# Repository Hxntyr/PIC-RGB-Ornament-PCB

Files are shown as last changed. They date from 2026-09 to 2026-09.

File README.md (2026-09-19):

# PIC RGB Ornament PCB

A template for making — and a collection of — small RGB LED PCB ornaments.

The core circuit uses a PIC12F1572, CR2450R coin cell, and MCP1640 boost converter to drive 24 low-current RGB LEDs through three shared PWM channels. It is intended to be reused across different board shapes, artwork, and LED layouts without redesigning the electronics each time.

Copy the core project, make your own layout, generate the manufacturing files, and send it off for PCBA — or [purchase the components and assemble it yourself](https://www.digikey.com/en/mylists/list/D7LT6KEKSW).

<p align="center">
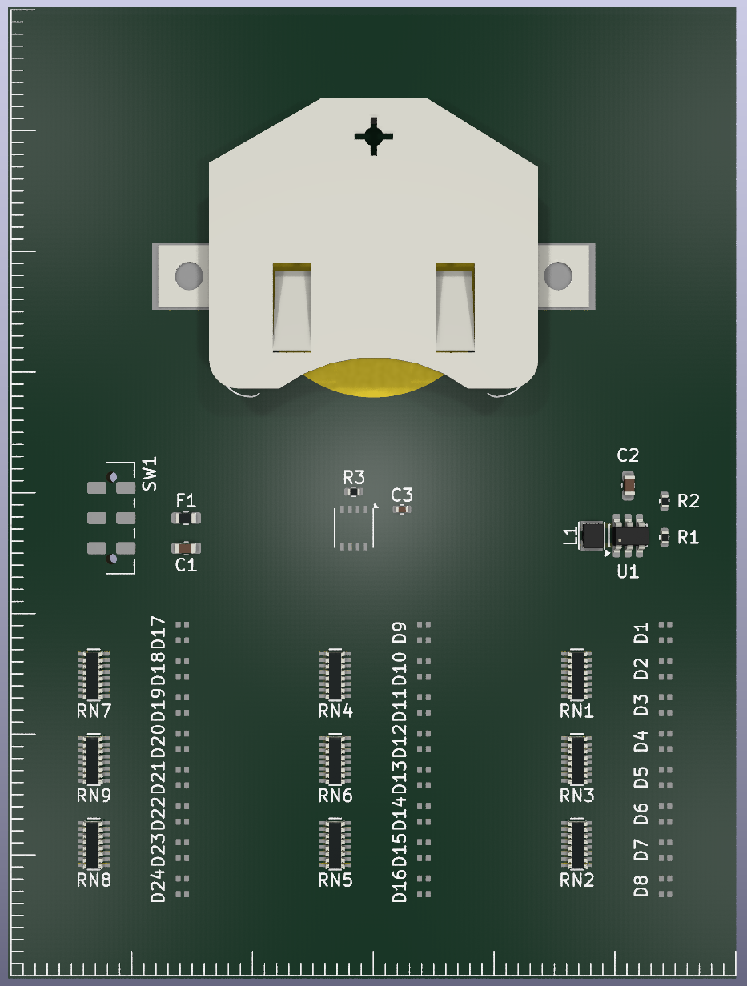
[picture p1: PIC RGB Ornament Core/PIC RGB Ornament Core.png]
PIC RGB Ornament Core
  
</p>

## What's Included

The [`PIC RGB Ornament Core`](PIC%20RGB%20Ornament%20Core/) folder contains the reusable KiCad project.

Reference files:

* [`PIC RGB Ornament Core_Schematic.pdf`](PIC%20RGB%20Ornament%20Core/PIC%20RGB%20Ornament%20Core_Schematic.pdf) — schematic
* [`PIC RGB Ornament Core_PCB.pdf`](PIC%20RGB%20Ornament%20Core/PIC%20RGB%20Ornament%20Core_PCB.pdf) — component layout with a millimeter scale for quick size reference
* [`PIC RGB Ornament Core.png`](PIC%20RGB%20Ornament%20Core/PIC%20RGB%20Ornament%20Core.png) — 3D viewer reference

Custom footprints are stored in the repository-level [`HX.pretty`](HX.pretty/) library. Each included KiCad project references this library through its local `fp-lib-table`.

The core [`PCBA`](PIC%20RGB%20Ornament%20Core/PCBA/) folder contains files that can generally be reused between designs:

* `BOM.xlsx`
* `FIRMWARE.zip`

The supplied firmware continuously cycles through a slow rainbow at conservative brightness. The PIC is intended to be programmed during assembly, so the finished ornament requires no configuration.

## Making an Ornament

Clone or download the repository and make a copy of the `PIC RGB Ornament Core` project, or use one of the existing ornaments as a starting point.

The electrical design can generally remain unchanged. Modify the board outline, component placement, LED arrangement, artwork, mounting features, and routing as needed for the new design.

If additional custom footprints are required, add them to the root `HX.pretty` library. Projects located one directory below the repository root can use the same `fp-lib-table` entry:

```scheme
(fp_lib_table
  (version 7)
  (lib (name "HX")(type "KiCad")(uri "${KIPRJMOD}/../HX.pretty")(options "")(descr "Project custom footprints"))
)
```

## Preparing a Layout for PCBA

The BOM and firmware can normally be reused as long as the circuit and component selections remain unchanged.

The remaining manufacturing files are layout-specific and should be regenerated for each ornament.

### Gerbers and Drill Files

From KiCad PCB Editor:

`File → Fabrication Outputs → Gerbers`

Export the required copper, solder mask, silkscreen, paste, and `Edge.Cuts` layers, then generate the Excellon drill files.

Zip the Gerber and drill outputs together for fabrication.

### CPL / Pick-and-Place

From KiCad PCB Editor:

`File → Fabrication Outputs → Component Placement`

Export the placement file in millimeters with reference designator, X/Y coordinates, rotation, and board side.

PCBWay refers to this as the **CPL** or centroid file.

### Assembly Drawings

Plot `F.Fab` and `B.Fab` as PDFs with the board outline visible.

These provide a simple component-location and orientation reference for assembly.

### BOM

The baseline BOM is included at:

`PIC RGB Ornament Core/PCBA/BOM.xlsx`

Regenerate or edit it if component values, part numbers, or designators change.

### PIC Firmware

Production firmware is included at:

`PIC RGB Ornament Core/PCBA/FIRMWARE.zip`

For turnkey assembly, program:

`U2 — PIC12F1572T-I/MF`

using the supplied `.hex` file before assembly.

Example production note:

> Program U2 before assembly using the supplied HEX file. After assembly, power the board and verify that all 24 RGB LEDs smoothly cycle through the rainbow.

## Example

[`HappyBirthdayMickey_A`](HappyBirthdayMickey_A/) is an example ornament built from the core design.

Its `PCBA` folder contains a complete set of layout-specific production files:

* Gerber and drill ZIP
* BOM
* CPL / pick-and-place file
* assembly drawing PDFs
* firmware

These are included as a reference for what a completed manufacturing package looks like rather than as production files for the generic core.

## Notes

The default firmware intentionally runs the LEDs fairly dim to reduce coin-cell current and keep the ornament comfortable to view in a dark room.

The CR2450R battery should be installed **after** PCB assembly and should not go through reflow.

## License

This project is released under the **CC0 1.0 Universal Public Domain Dedication**.

Use it, modify it, manufacture it, remix it, or turn it into something completely different.

See [`LICENSE`](LICENSE).

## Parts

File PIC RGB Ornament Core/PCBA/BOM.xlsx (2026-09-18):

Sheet: PCBWay BOM
PIC RGB Ornament PCB — PCBWay Assembly BOM
14 unique assembly line items • 45 total placed components • CR2450R battery excluded from reflow BOM
Item | Designator | Qty | Value | Description | Manufacturer | MFG Part Number | Package / Footprint | Assembly Type | Assembly Notes | Datasheet
1 | U1 | 1 | MCP1640 | 500 kHz synchronous PWM/PFM boost regulator, true output disconnect | Microchip Technology | MCP1640T-I/CHY | SOT-23-6 | SMD |  | https://ww1.microchip.com/downloads/aemDocuments/documents/APID/ProductDocuments/DataSheets/MCP1640-Family-Data-Sheet-DS20002234E.pdf
2 | U2 | 1 | PIC12F1572 | 8-bit MCU with 3× 16-bit PWM channels and internal oscillator | Microchip Technology | PIC12F1572T-I/MF | DFN-8, 3×3 mm, 0.65 mm pitch | SMD | PROGRAM BEFORE ASSEMBLY. Firmware file: PIC_RGB_Ornament.hex. Do not substitute MCU without approval. | https://ww1.microchip.com/downloads/en/DeviceDoc/40001723D.pdf
3 | D1-D24 | 24 | RGB | Low-current common-anode RGB LED, 1.6×0.8×0.5 mm | Kingbright | APHF1608LSEEQBDZGKC | 4-SMD, 1.6×0.8 mm | SMD | Observe polarity/orientation. Exact optical part preferred. | https://www.kingbrightusa.com/images/catalog/SPEC/APHF1608LSEEQBDZGKC.pdf
4 | RN1,RN4,RN7 | 3 | 8.2 kΩ ×8 | 8 isolated resistor elements; red LED current limiting | Panasonic | EXB2HV822JV | EXB-2HV, 16-pad resistor array | SMD |  | https://industrial.panasonic.com/cdbs/www-data/pdf/AOC0000/AOC0000C14.pdf
5 | RN2,RN3,RN5,RN6,RN8,RN9 | 6 | 3.9 kΩ ×8 | 8 isolated resistor elements; green/blue LED current limiting | Panasonic | EXB2HV392JV | EXB-2HV, 16-pad resistor array | SMD |  | https://industrial.panasonic.com/cdbs/www-data/pdf/AOC0000/AOC0000C14.pdf
6 | R1 | 1 | 309 kΩ | MCP1640 feedback lower resistor, 1% | Yageo | RC0402FR-07309KL | 0402 / 1005 metric | SMD |  | https://yageogroup.com/content/datasheet/asset/file/PYU-RC_GROUP_51_ROHS_L
7 | R2 | 1 | 604 kΩ | MCP1640 feedback upper resistor, 1% | Yageo | RC0402FR-07604KL | 0402 / 1005 metric | SMD |  | https://yageogroup.com/content/datasheet/asset/file/PYU-RC_GROUP_51_ROHS_L
8 | R3 | 1 | 10 kΩ | PIC MCLR pull-up resistor, 1% | Yageo | RC0402FR-0710KL | 0402 / 1005 metric | SMD |  | https://yageogroup.com/content/datasheet/asset/file/PYU-RC_GROUP_51_ROHS_L
9 | C1,C2 | 2 | 10 µF | Boost converter input/output MLCC, 10 V X5R | Murata | GRM188R61A106ME69 | 0603 / 1608 metric | SMD |  | https://mm.digikey.com/Volume0/opasdata/d220001/medias/docus/8942/490_Chip_Multilayer_CAT2021_MLCC.pdf
10 | C3 | 1 | 100 nF | PIC local VDD decoupling MLCC | Murata | GRM155R71C104KA88J | 0402 / 1005 metric | SMD |  | https://mm.digikey.com/Volume0/opasdata/d220001/medias/docus/8942/490_Chip_Multilayer_CAT2021_MLCC.pdf
11 | L1 | 1 | 4.7 µH | Shielded boost-converter inductor, 1.1 A | Murata | LQM2MPN4R7MG0L | 2.0×1.6 mm power inductor | SMD |  | https://pim.murata.com/asset/pim4/inductor/JELF243B-0022_PDF_INDUCTOR
12 | F1 | 1 | 50 mA hold | Resettable PPTC battery protection fuse | Eaton | PTS060315V005 | 0603 / 1608 metric | SMD |  | https://www.eaton.com/content/dam/eaton/products/electronic-components/resources/data-sheet/eaton-pts0603-surface-mount-resettable-fuse-data-sheet-elx1046-en.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
13 | SW1 | 1 | SPDT ON-ON | Right-angle SMT slide power switch | C&K | JS102011JAQN | JS series right-angle SMT | SMD | Observe mechanical orientation at board edge. | https://www.littelfuse.com/assetdocs/littelfuse-c-k-slide-js-series-datasheet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
14 | BT1 | 1 | 3088TR | SMT coin-cell holder/retainer for 24.5 mm cell | Keystone Electronics | 3088TR | SMT CR2450 holder | SMD | Battery itself is not reflow assembled; install CR2450R after PCBA. | https://www.keyelco.com/userAssets/file/K75p11.pdf

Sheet: Non-PCBA
Non-PCBA / Production Items
Item | Qty | Description | Manufacturer | Part Number | Handling / Notes | Datasheet
CR2450R battery | 1 | 3 V high-drain lithium coin cell, ~500 mAh | Murata | CR2450R | Do not send through reflow. Install after assembly / before gifting. Recommended cell for the design. | https://www.murata.com/-/media/webrenewal/products/batteries/micro/cr/high-drain/ds-cr2450r-004-je_202307.ashx
PIC firmware | 1 | Production firmware image for U2 | Project file | PIC_RGB_Ornament.hex | Provide to PCBWay with instruction to program U2 before assembly.

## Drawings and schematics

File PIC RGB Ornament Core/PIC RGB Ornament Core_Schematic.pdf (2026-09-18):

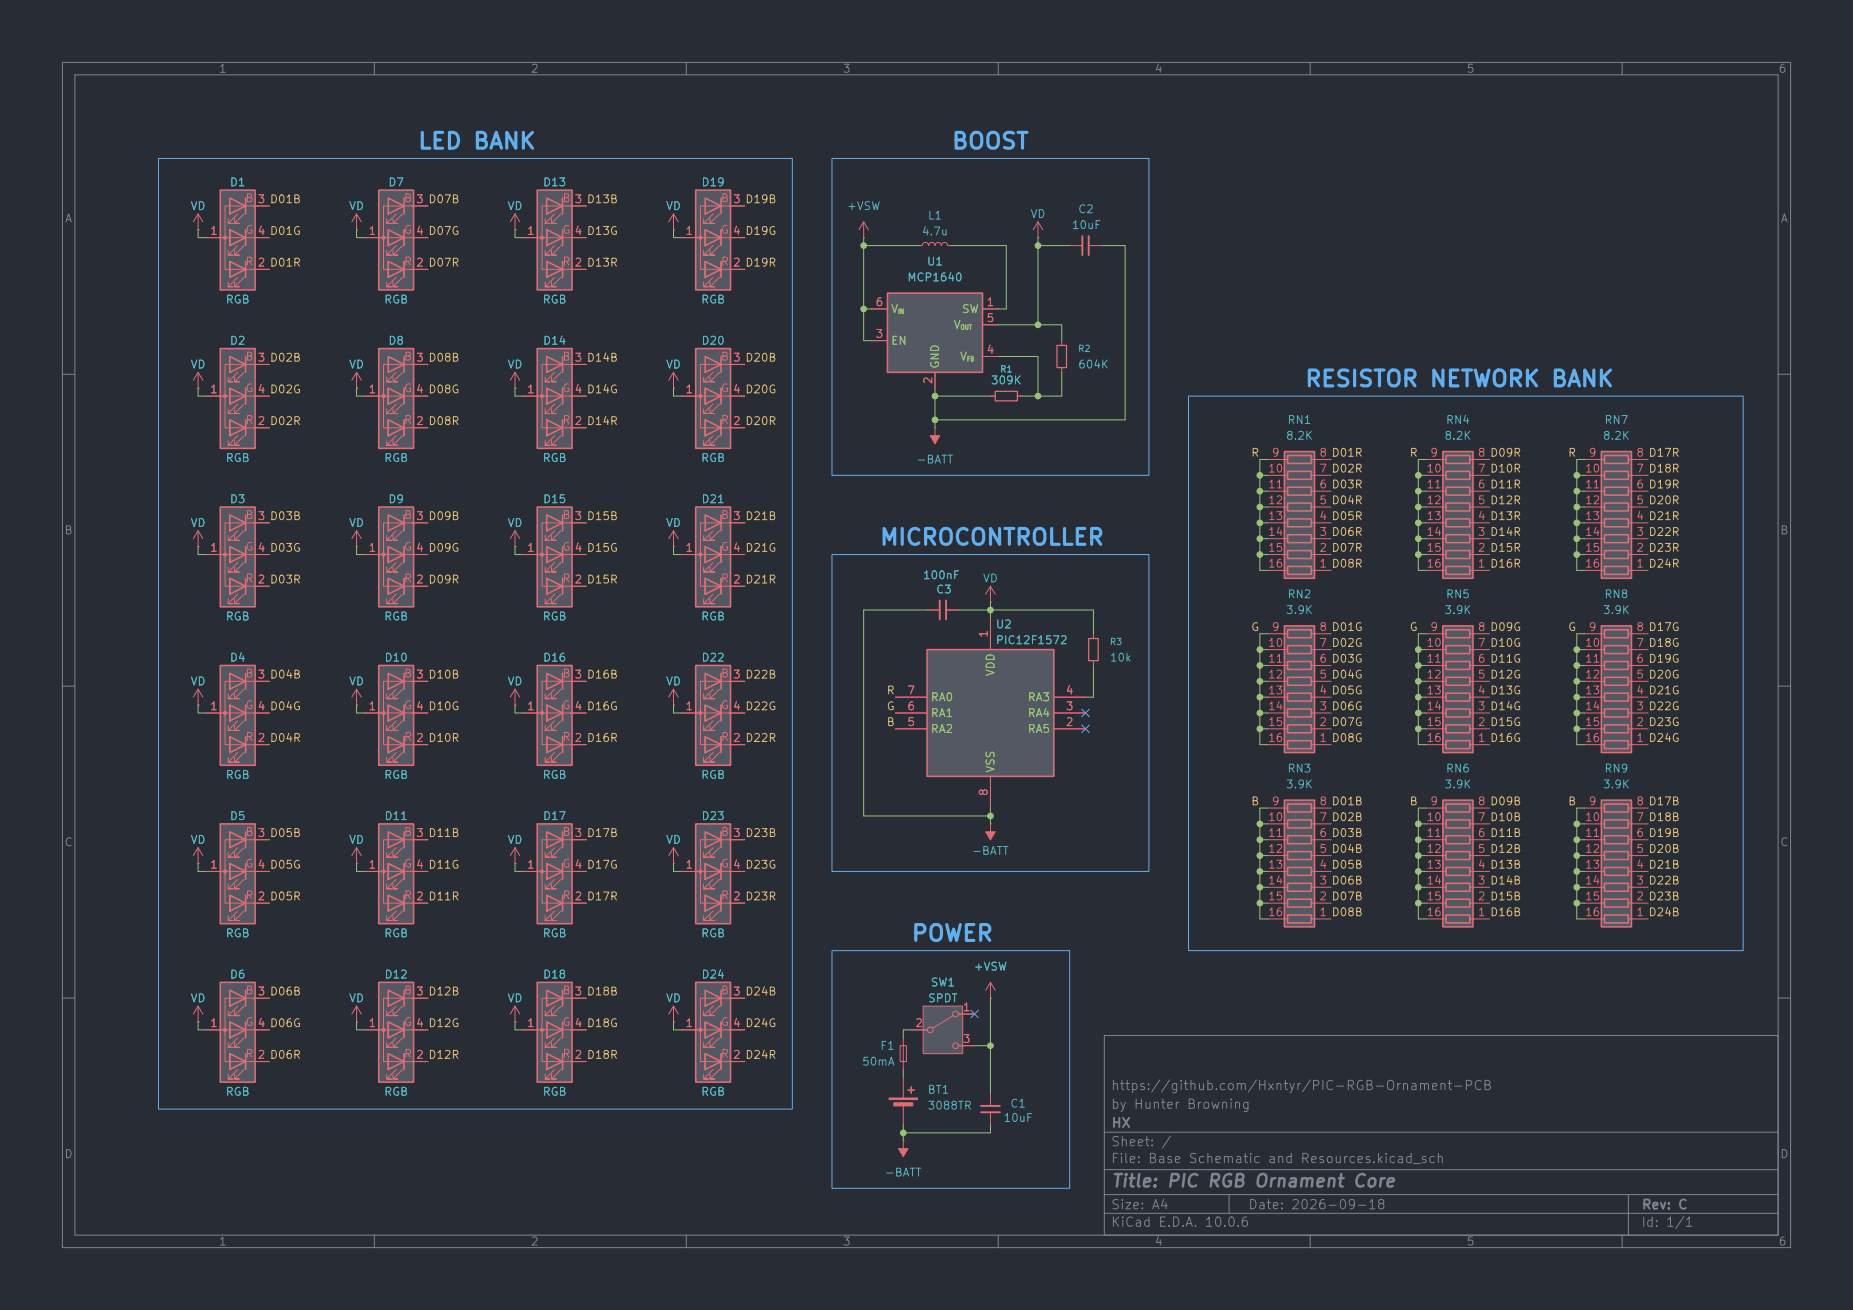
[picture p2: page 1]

https://github.com/Hxntyr/PIC-RGB-Ornament-PCB
by Hunter Browning
Sheet: /
File: Base Schematic and Resources.kicad_sch
Title: PIC RGB Ornament Core

Size: A4 | Rev: C
KiCad E.D.A. 10.0.6 | Id: 1/1

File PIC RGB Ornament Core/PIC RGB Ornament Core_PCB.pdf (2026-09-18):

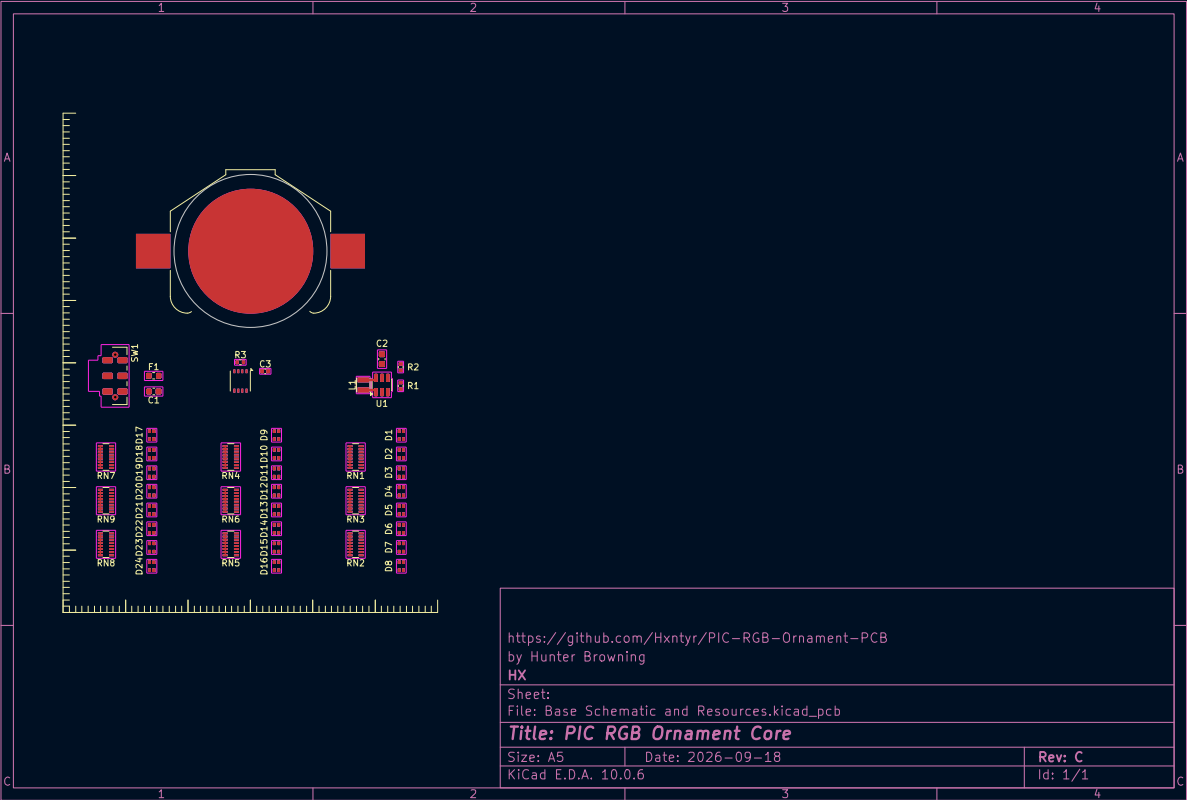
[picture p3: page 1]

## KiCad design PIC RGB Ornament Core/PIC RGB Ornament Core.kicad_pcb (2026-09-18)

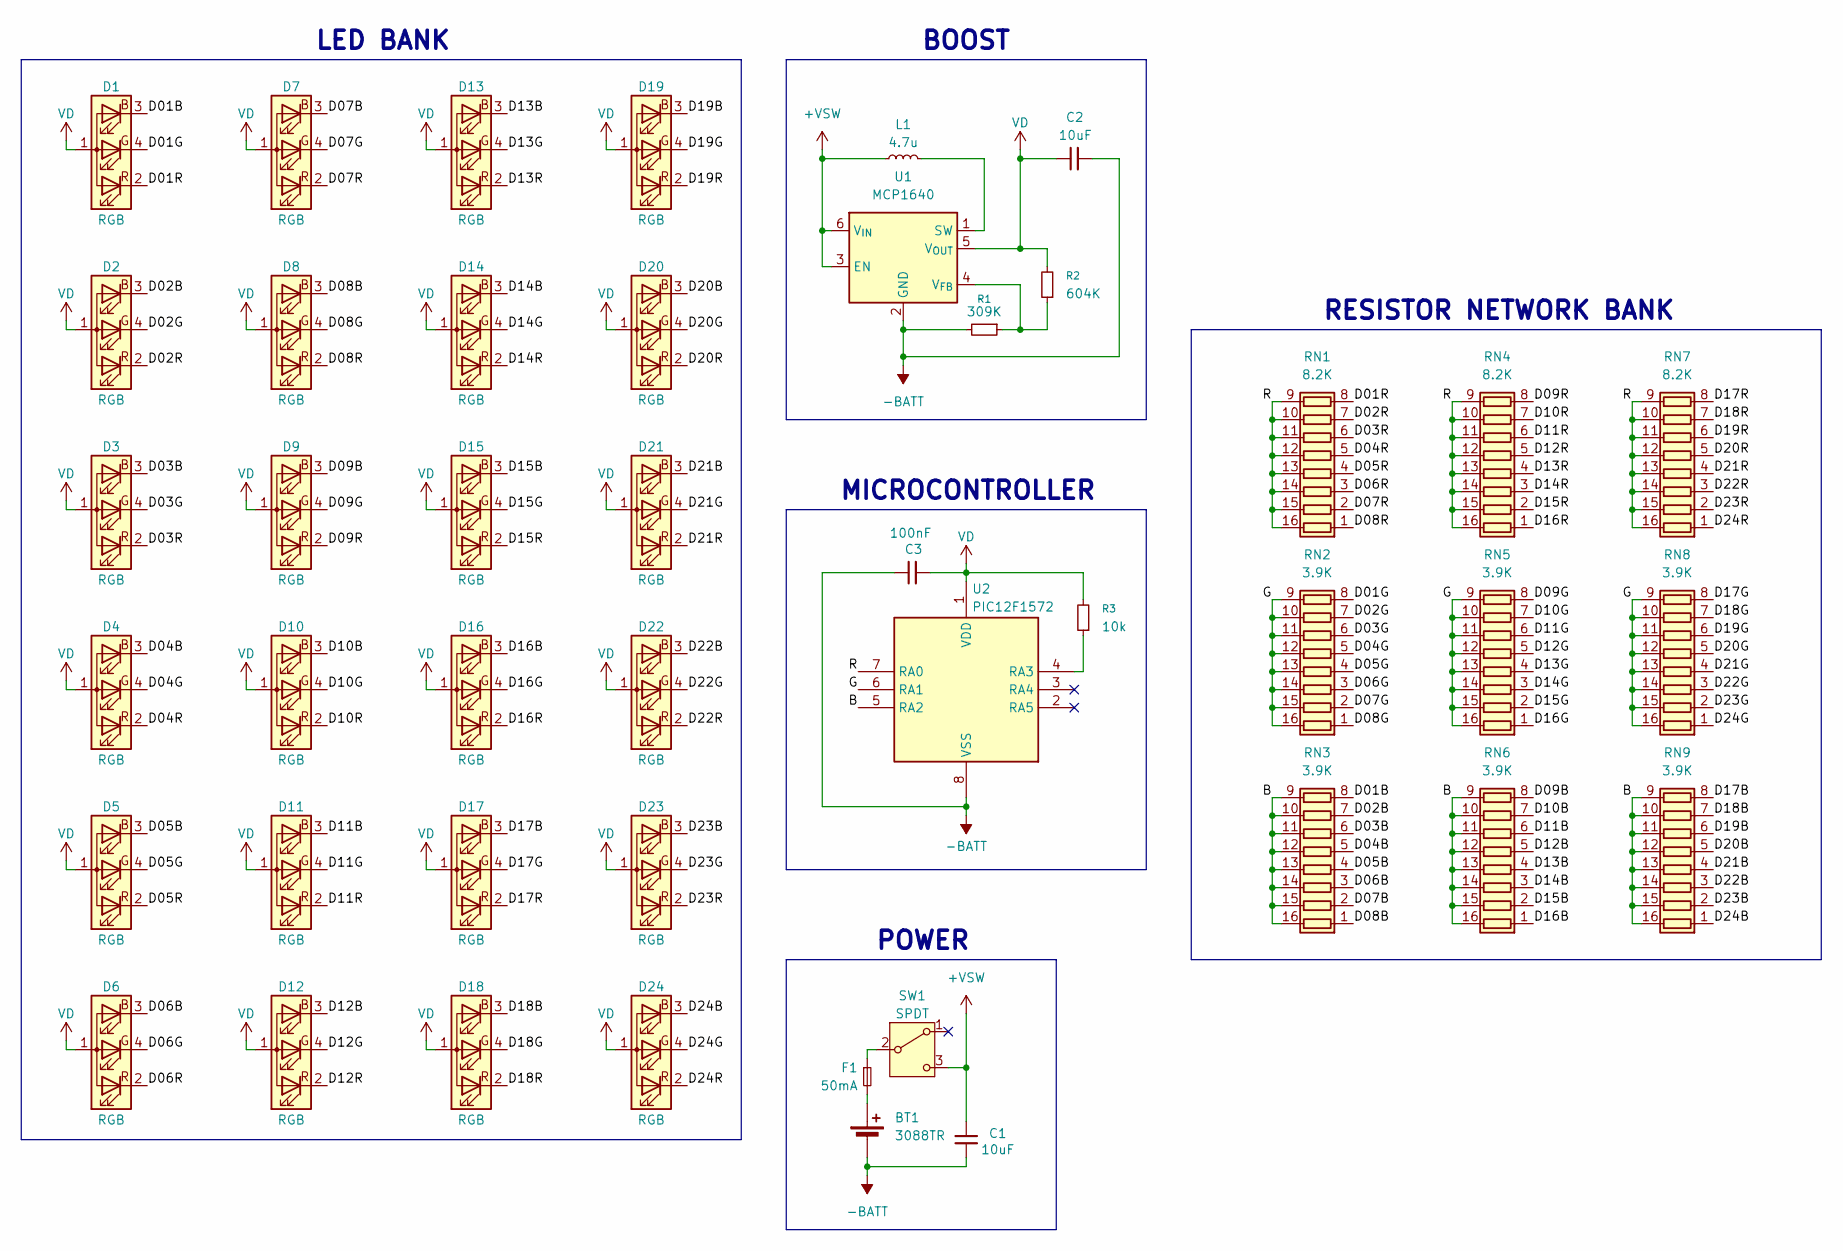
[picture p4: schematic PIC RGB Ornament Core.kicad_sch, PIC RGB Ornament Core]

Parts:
BT1: 3088TR; Keystone_3088TR; MPN 3088TR
C1, C2: 10uF; C_0603_1608Metric; MPN GRM188R61A106ME69
C3: 100nF; C_0402_1005Metric; MPN GRM155R71C104KA88J
D1, D2, D3, D4, D5, D6, D7, D8, D9, D10, D11, D12, D13, D14, D15, D16, D17, D18, D19, D20, D21, D22, D23, D24: RGB; Kingbright_APHF1608LSEEQBDZGKC; MPN APHF1608LSEEQBDZGKC
F1: 50mA; Fuse_0603_1608Metric; MPN PTS060315V005
L1: 4.7u; Murata_LQM2MPN4R7MG0L; MPN LQM2MPN4R7MG0L
R1: 309K; R_0402_1005Metric; MPN RC0402FR-07309KL
R2: 604K; R_0402_1005Metric; MPN RC0402FR-07604KL
R3: 10k; R_0402_1005Metric; MPN RC0402FR-0710KL
RN1, RN4, RN7: 8.2K; R_Array_Convex_8x0602; MPN EXB2HV822JV
RN2, RN3, RN5, RN6, RN8, RN9: 3.9K; R_Array_Convex_8x0602; MPN EXB2HV392JV
SW1: SPDT; CK_JS102011JAQN; MPN JS102011JAQN
U1: MCP1640; SOT-23-6; MPN MCP1640T-I/CHY
U2: PIC12F1572; Microchip_PIC12F1572T-IMF; MPN PIC12F1572T-I/MF

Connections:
+VSW: C1.1, L1.2, SW1.3 (C), U1.3 (EN), U1.6 (V_{IN})
-BATT: BT1.2 (-), C1.2, C2.2, C3.2, R1.2, U1.2 (GND), U2.8 (VSS)
/B: RN3.9 (R8.2), RN3.10 (R7.2), RN3.11 (R6.2), RN3.12 (R5.2), RN3.13 (R4.2), RN3.14 (R3.2), RN3.15 (R2.2), RN3.16 (R1.2), RN6.9 (R8.2), RN6.10 (R7.2), RN6.11 (R6.2), RN6.12 (R5.2), RN6.13 (R4.2), RN6.14 (R3.2), RN6.15 (R2.2), RN6.16 (R1.2), RN9.9 (R8.2), RN9.10 (R7.2), RN9.11 (R6.2), RN9.12 (R5.2), RN9.13 (R4.2), RN9.14 (R3.2), RN9.15 (R2.2), RN9.16 (R1.2), U2.5 (RA2)
/D01B: D1.3 (BK), RN3.8 (R8.1)
/D01G: D1.4 (GK), RN2.8 (R8.1)
/D01R: D1.2 (RK), RN1.8 (R8.1)
/D02B: D2.3 (BK), RN3.7 (R7.1)
/D02G: D2.4 (GK), RN2.7 (R7.1)
/D02R: D2.2 (RK), RN1.7 (R7.1)
/D03B: D3.3 (BK), RN3.6 (R6.1)
/D03G: D3.4 (GK), RN2.6 (R6.1)
/D03R: D3.2 (RK), RN1.6 (R6.1)
/D04B: D4.3 (BK), RN3.5 (R5.1)
/D04G: D4.4 (GK), RN2.5 (R5.1)
/D04R: D4.2 (RK), RN1.5 (R5.1)
/D05B: D5.3 (BK), RN3.4 (R4.1)
/D05G: D5.4 (GK), RN2.4 (R4.1)
/D05R: D5.2 (RK), RN1.4 (R4.1)
/D06B: D6.3 (BK), RN3.3 (R3.1)
/D06G: D6.4 (GK), RN2.3 (R3.1)
/D06R: D6.2 (RK), RN1.3 (R3.1)
/D07B: D7.3 (BK), RN3.2 (R2.1)
/D07G: D7.4 (GK), RN2.2 (R2.1)
/D07R: D7.2 (RK), RN1.2 (R2.1)
/D08B: D8.3 (BK), RN3.1 (R1.1)
/D08G: D8.4 (GK), RN2.1 (R1.1)
/D08R: D8.2 (RK), RN1.1 (R1.1)
/D09B: D9.3 (BK), RN6.8 (R8.1)
/D09G: D9.4 (GK), RN5.8 (R8.1)
/D09R: D9.2 (RK), RN4.8 (R8.1)
/D10B: D10.3 (BK), RN6.7 (R7.1)
/D10G: D10.4 (GK), RN5.7 (R7.1)
/D10R: D10.2 (RK), RN4.7 (R7.1)
/D11B: D11.3 (BK), RN6.6 (R6.1)
/D11G: D11.4 (GK), RN5.6 (R6.1)
/D11R: D11.2 (RK), RN4.6 (R6.1)
/D12B: D12.3 (BK), RN6.5 (R5.1)
/D12G: D12.4 (GK), RN5.5 (R5.1)
/D12R: D12.2 (RK), RN4.5 (R5.1)
/D13B: D13.3 (BK), RN6.4 (R4.1)
/D13G: D13.4 (GK), RN5.4 (R4.1)
/D13R: D13.2 (RK), RN4.4 (R4.1)
/D14B: D14.3 (BK), RN6.3 (R3.1)
/D14G: D14.4 (GK), RN5.3 (R3.1)
/D14R: D14.2 (RK), RN4.3 (R3.1)
/D15B: D15.3 (BK), RN6.2 (R2.1)
/D15G: D15.4 (GK), RN5.2 (R2.1)
/D15R: D15.2 (RK), RN4.2 (R2.1)
/D16B: D16.3 (BK), RN6.1 (R1.1)
/D16G: D16.4 (GK), RN5.1 (R1.1)
/D16R: D16.2 (RK), RN4.1 (R1.1)
/D17B: D17.3 (BK), RN9.8 (R8.1)
/D17G: D17.4 (GK), RN8.8 (R8.1)
/D17R: D17.2 (RK), RN7.8 (R8.1)
/D18B: D18.3 (BK), RN9.7 (R7.1)
/D18G: D18.4 (GK), RN8.7 (R7.1)
/D18R: D18.2 (RK), RN7.7 (R7.1)
/D19B: D19.3 (BK), RN9.6 (R6.1)
/D19G: D19.4 (GK), RN8.6 (R6.1)
/D19R: D19.2 (RK), RN7.6 (R6.1)
/D20B: D20.3 (BK), RN9.5 (R5.1)
/D20G: D20.4 (GK), RN8.5 (R5.1)
/D20R: D20.2 (RK), RN7.5 (R5.1)
/D21B: D21.3 (BK), RN9.4 (R4.1)
/D21G: D21.4 (GK), RN8.4 (R4.1)
/D21R: D21.2 (RK), RN7.4 (R4.1)
/D22B: D22.3 (BK), RN9.3 (R3.1)
/D22G: D22.4 (GK), RN8.3 (R3.1)
/D22R: D22.2 (RK), RN7.3 (R3.1)
/D23B: D23.3 (BK), RN9.2 (R2.1)
/D23G: D23.4 (GK), RN8.2 (R2.1)
/D23R: D23.2 (RK), RN7.2 (R2.1)
/D24B: D24.3 (BK), RN9.1 (R1.1)
/D24G: D24.4 (GK), RN8.1 (R1.1)
/D24R: D24.2 (RK), RN7.1 (R1.1)
/G: RN2.9 (R8.2), RN2.10 (R7.2), RN2.11 (R6.2), RN2.12 (R5.2), RN2.13 (R4.2), RN2.14 (R3.2), RN2.15 (R2.2), RN2.16 (R1.2), RN5.9 (R8.2), RN5.10 (R7.2), RN5.11 (R6.2), RN5.12 (R5.2), RN5.13 (R4.2), RN5.14 (R3.2), RN5.15 (R2.2), RN5.16 (R1.2), RN8.9 (R8.2), RN8.10 (R7.2), RN8.11 (R6.2), RN8.12 (R5.2), RN8.13 (R4.2), RN8.14 (R3.2), RN8.15 (R2.2), RN8.16 (R1.2), U2.6 (RA1)
/R: RN1.9 (R8.2), RN1.10 (R7.2), RN1.11 (R6.2), RN1.12 (R5.2), RN1.13 (R4.2), RN1.14 (R3.2), RN1.15 (R2.2), RN1.16 (R1.2), RN4.9 (R8.2), RN4.10 (R7.2), RN4.11 (R6.2), RN4.12 (R5.2), RN4.13 (R4.2), RN4.14 (R3.2), RN4.15 (R2.2), RN4.16 (R1.2), RN7.9 (R8.2), RN7.10 (R7.2), RN7.11 (R6.2), RN7.12 (R5.2), RN7.13 (R4.2), RN7.14 (R3.2), RN7.15 (R2.2), RN7.16 (R1.2), U2.7 (RA0)
unnamed: BT1.1 (+), F1.2
unnamed: F1.1, SW1.2 (B)
unnamed: L1.1, U1.1 (SW)
unnamed: R1.1, R2.1, U1.4 (V_{FB})
unnamed: R3.1, U2.4 (RA3)
VD: C2.1, C3.1, D1.1 (A), D2.1 (A), D3.1 (A), D4.1 (A), D5.1 (A), D6.1 (A), D7.1 (A), D8.1 (A), D9.1 (A), D10.1 (A), D11.1 (A), D12.1 (A), D13.1 (A), D14.1 (A), D15.1 (A), D16.1 (A), D17.1 (A), D18.1 (A), D19.1 (A), D20.1 (A), D21.1 (A), D22.1 (A), D23.1 (A), D24.1 (A), R2.2, R3.2, U1.5 (V_{OUT}), U2.1 (VDD)

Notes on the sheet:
RESISTOR NETWORK BANK
BOOST
POWER
LED BANK
MICROCONTROLLER

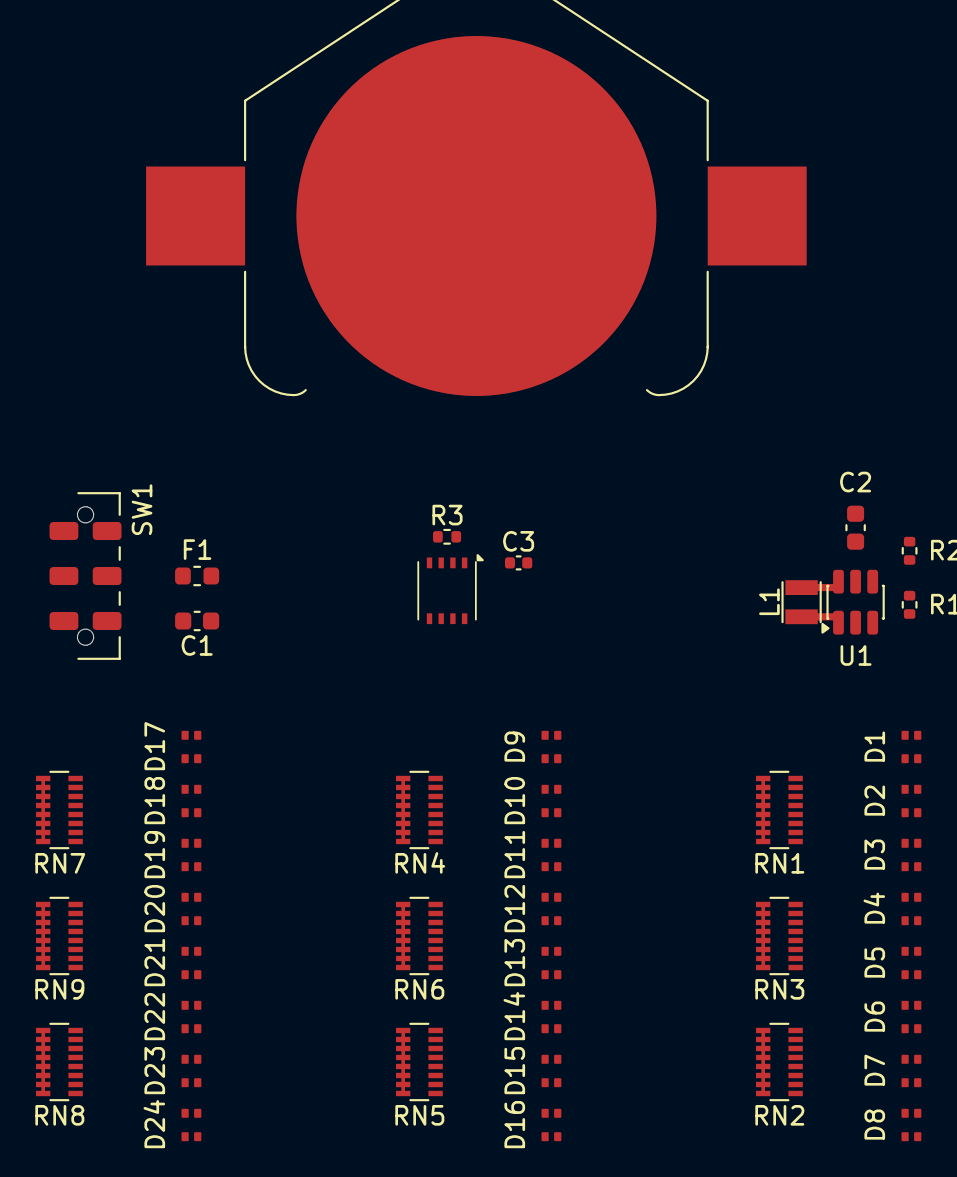
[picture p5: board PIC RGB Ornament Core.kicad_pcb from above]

Board: 2 copper layers, 45 parts (0 on the bottom side), 83 nets.
